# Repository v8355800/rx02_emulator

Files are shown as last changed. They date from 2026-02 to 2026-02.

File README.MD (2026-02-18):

<h1 align="center"> Эмулятор "ГМД-70"/"ГМД-7012" для ЭВМ "Электроника-60"</h1>
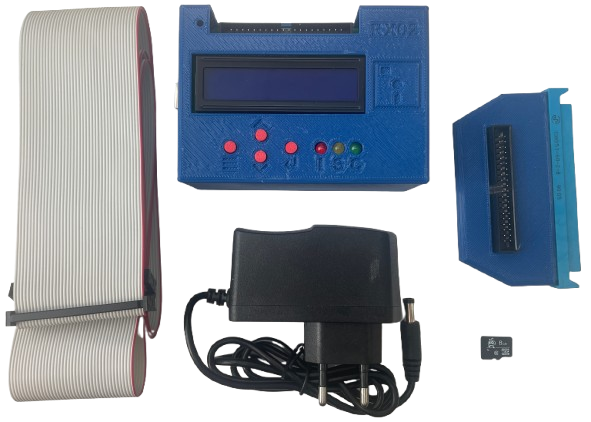
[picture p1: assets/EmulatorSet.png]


##  Оглавление
* [Описание](#description)
* [Комплектация](#equipment)
* [Принцип работы](#operating)
* [Изготовление](#manufacturing)
    * [Покупка компонентов](#manufacturing_buy)
    * [Печатные платы](#manufacturing_pcb)
        * ['Адаптер'](#manufacturing_pcb_adapter)
        * ['Эмулятор'](#manufacturing_pcb_emulator)
    * [Сборка 'Адаптера'](#manufacturing_adapter_assembly)
    * [Сборка 'Эмулятора'](#manufacturing_emulator_assembly)
    * [Жгут](#manufacturing_cable)
* [Корпус](#manufacturing_case)
* [Прошивка](#firmware)
* [Проверка работоспособности](#test)

## Описание
Устройство позволяет отказаться от использования накопителя `"ГМД-70"`/`"ГМД-7012"` (далее НГМД) в составе ЭВМ `"Электроника-60"`, заменив загрузку с дискет на загрузку с образов.
Образы дисков хранятся на `MicroSD` карте. 
"Эмулятор" представляет собой `"Arduino Shield"` (плата расширения) на базе `Arduino Mega2560`.

Ключевое преимущество прибора — автономность, обеспечивающая выбор нужных образов напрямую через само устройство, не требуя подключения к компьютеру.

## Комплектация
- "Эмулятор"
- "Адаптер" (для подключения "Эмулятора" к плате "И-4" в составе ЭВМ)
- Жгут (соединяет эмулятор с адаптером)
- Блок питания
    * 9V DC
    * &#8805;500mA
    * Jack 5.5x2.1
    * полярность - прямая ("+" по центру)
- MicroSD card
    * 8GB
    * SDHC

## Принцип работы
Для понимания можно провести простую аналогию: 
при использовании реального накопителя оператор устанавливает дискету в один или оба доступных отсеков.
То же самое и с эмулятором. Через меню выбирается образ, который устанавливается в виртуальный отсек `[0]` или `[1]`. 
Проще говоря: вместо установки дискет указывается нужный образ в выбранном отсеке.

> [!TIP]  
> Для ЭВМ данный эмулятор выглядит точно так же как и физический накопитель. 

## Изготовление

### Покупка компонентов
Купить компоненты можно на "ChipDip", "Ozon", "WB", "Aliexpress".
Обычно удобно всю мелочевку купить на "ChipDip", а остальное на маркетплейсах.

BOM-файл "Адаптер": [Интерактивный](https://v8355800.github.io/rx02_emulator/assets/bom/RX02_Adapter_ibom_v1.1.html) / [CSV](assets/bom/RX02_Emulator_bom_v1.2.csv)  
BOM-файл "Эмулятор": [Интерактивный](https://v8355800.github.io/rx02_emulator/assets/bom/RX02_Emulator_ibom_v1.2.html) / [CSV](assets/bom/RX02_Emulator_bom_v1.2.csv)

[Ссылка на "Корзину" в "ChipDip"](https://www.chipdip.ru/cart/share/P7Al1Tl6KI5sdudKpMeFdJT3irWuv8lbFa3mm7L9Bp3oRmtGSJEMUTi2QN5kUsKruICHdr5GWGdcOhvIBDb02yR9f8PagUMRVEMTWNeX60IBFPVu2m0RJdy3djSNJDYW2)  
[Excel-таблица покупок](assets/bom/Buy.xlsx)

> [!NOTE]  
> Количество компонентов указано для 10 комплектов.

### Печатные платы
"Адаптер" и "Эмулятор" выполнены в виде двусторонних печатных плат под THT(выводные) компоненты, что упрощает процесс ручной сборки.
Размер плат не превышает `100x100mm`, поскольку многие производства предлагают существенные скидки на платы такого формата.
Заказать печатные платы можно на любом производстве (Резонит, JLCPCB и т.д.).
Параметры: `2 слоя, FR4 1.6mm, 1 Oz (35 µm), HASL, Зеленая маска, Белая шелкография`.  
Gerber-файлы находятся в папке ["gerbers"](gerbers/).

**"Адаптер" - [Gerber-файлы](gerbers/rx02-emulator-adapter_v1.1.zip)**
|Верх|Низ|
|:-:|:-:|
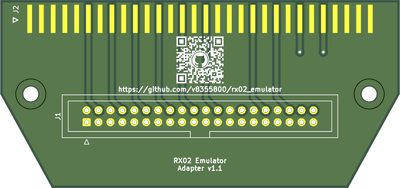
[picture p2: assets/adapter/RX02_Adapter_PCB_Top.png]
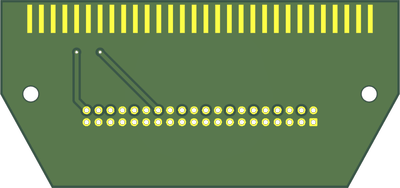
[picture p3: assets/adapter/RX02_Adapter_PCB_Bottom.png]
|||

**"Эмулятор" - [Gerber-файлы](gerbers/rx02-emulator-mega-shield_v1.2.zip)**
|Верх|Низ|
|:-:|:-:|
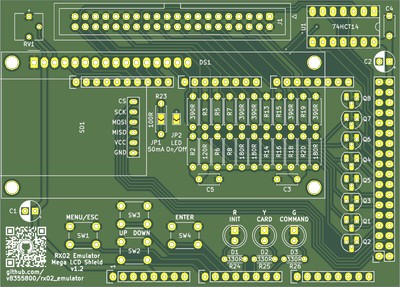
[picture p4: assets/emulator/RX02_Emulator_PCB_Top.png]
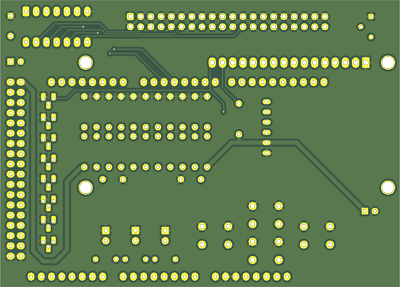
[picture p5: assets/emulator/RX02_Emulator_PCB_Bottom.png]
|||

### Сборка "Адаптера"
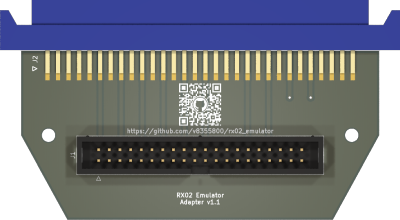
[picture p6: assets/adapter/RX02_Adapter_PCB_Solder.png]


### Сборка "Эмулятора"
|Верх|Низ|
|:-:|:-:|
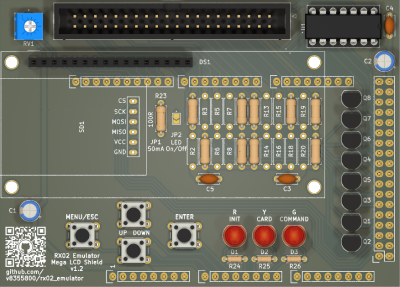
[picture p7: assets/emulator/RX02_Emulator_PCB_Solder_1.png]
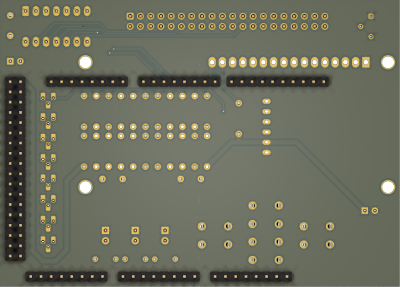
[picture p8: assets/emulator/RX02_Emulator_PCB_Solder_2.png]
|||

**"U1" Микросхема**

||Микросхема|
|:-:|:-|
|Предпочтительно|`74HCT14`, `74AHCT14`|
|Приемлемо|`74HC14`, `74AHC14`|
|Не подходит|`7414`, `74LS14`, `74ALS14`, `74xx04` (any technology)|

Схема устанавливается по ключу (полукруглая выемка на микросхеме). 

**"R1-R22" Termination resistor table**\
Шелкография на плате облегчает определение какие резисторы требуется устанавливать. Если указан номинал, то резистор устанавливается, если нет, то установка не производится.

|Сигнал|Резистор|Номинал||Сигнал|Резистор|Номинал|
|:-----:|:---:|:----:|-|:-----:|:---:|:----:|
|RX_DMA_MODE_H|R1|390||RX_DONE_L|R13|-|
||R2|-|||R14|-|
|RX_AC_L|R3|-||RX_XFER_RQST_L|R15|-|
||R4|120|||R16|-|
|RX_OUT_L|R5|-||RX_INIT_L|R17|390|
||R6|-|||R18|-|
|RX_SHIFT_L|R7|-||RX_ERROR_L|R19|-|
||R8|-|||R20|-|
|RX_12_BIT_L|R9|390||RX_RUN_L|R21|390|
||R10|180|||R22|180|
|RX_DATA_L|R11|390|
||R12|180|

**"D1-D3" Светодиоды**\
Длина ножки `Анода` светодиодов, указанных в `BOM` составляет `16мм`. Нужно запаять так, чтобы они максимально выступали над платой, что обеспечит совпадение с отверстиями в корпусе.

|Светодиод|Цвет|Назначение|Описание|
|:-:|:-:|:-:|:-:|
|D1|Красный|INIT|**ON** - `INIT` устанавливается хостом или ошибка в эмуляторе.<br>**OFF** - в начале команды.|
|D2|Желтый|CARD|**ON** - эмулятор обращается к `MicroSD` карте.<br>**OFF** в противном случае.|
|D3|Зеленый|COMMAND|**ON** - хост отправляет команду.<br>**OFF** - команда выполнена (`DONE` установлен).|

Во время нормальной работы `D2`, `D3` быстро мигают или в основном горят. Для команд, не связанных с хранением (например заполнение/очистка буфера) будет включен только `D3`.

**"JP1" Перемычка**  
Используется для регулирования тока подсветки экрана `LCD1602`.  
Замкнута - ток проходит без ограничений.  
Разомкнута - в цепь включается токоограничивающий резистор `R23`.  
Номинал `R23` составляет `100 Ом`, что обеспечивает максимальный ток подсветки — `50 мА`.  
По умолчанию перемычка не запаивается, резистор `R23` устанавливается.

**"JP2" Перемычка**  
Используется для выбора метода управления подсветкой дисплея `LCD1602`.  
Замкнута - подсветка дисплея постоянно включена, установка транзистора `Q8` не требуется.  
Разомкнута - подсветкой управляет Arduino, требуется установка транзистора `Q8`.  
По умолчанию перемычка не запаивается.

**"P1-P7" Штырьевые разъемы**  
`PLS`, `PLD` запаиваются с нижней стороны платы. С помощью кусачек нарезаются `PLS-40` и `PLD-40` нужной длины.
|Pos|Type|Num|
|:-:|:-:|:-:|
|P1|PLD|36|
|P5|PLS|10|
|P2-P4, P6-P7|PLS|8|

**"SD1" SPI адаптер карт MicroSD**
|MicroSD|Сборка 1|Сборка 2|
|:-:|:-:|:-:|
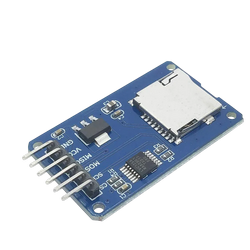
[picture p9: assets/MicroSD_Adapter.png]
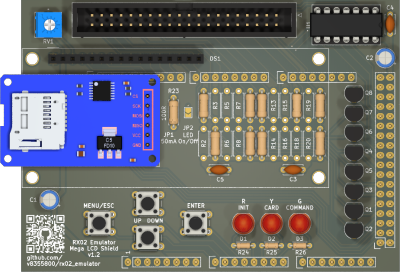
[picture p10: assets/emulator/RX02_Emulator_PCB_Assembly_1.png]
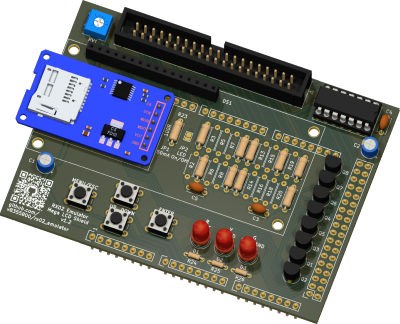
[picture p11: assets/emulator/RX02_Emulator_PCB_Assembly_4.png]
||||

Необходимо выпаять угловой разъем который установлен с завода на плате адаптера. На его место снизу запаять `PLS-6`. Затем впаять в печатную плату на место `SD1`. Нужно выдержать горизонтальность. Этого можно легко добиться, если во время пайки между платой и адаптером подложить спейсеры (черные квадратики которые можно снять с углового разъема, если вытащить пины).

> [!WARNING]
> Если при включении устройство зависает на экране с номером версии прошивки, то убедиться что `MicroSD` карта установлена.

**"DS1" Символьный дисплей LCD1602 (2 строки по 16 символов)**
|LCD1602|Сборка 1|
|:-:|:-:|
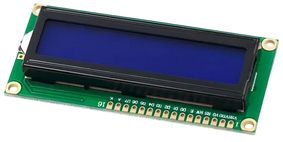
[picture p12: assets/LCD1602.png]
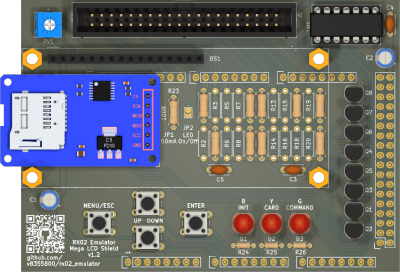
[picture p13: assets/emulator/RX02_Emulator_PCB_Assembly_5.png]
|||

|Сборка 2|Сборка 3|
|:-:|:-:|
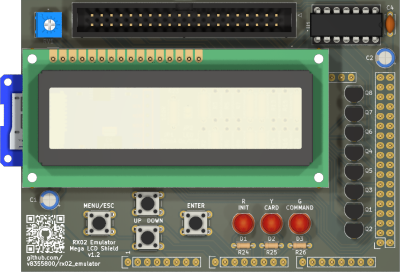
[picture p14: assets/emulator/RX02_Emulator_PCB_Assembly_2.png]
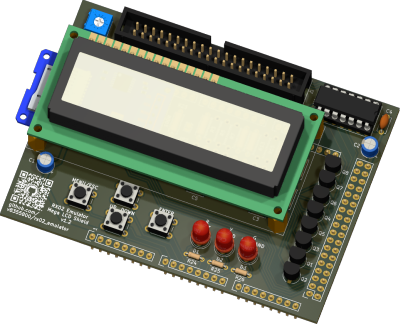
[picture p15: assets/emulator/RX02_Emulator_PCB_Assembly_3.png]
||

На место `DS1` печатной платы сверху запаять гнездо `PBS-16`. На `LCD1602` снизу запаять вилку `PLS-16`.
При установке дисплея на плату в четырех углах между платой и дисплеем установить стойки длиной `11мм`. Закрепить стойки к печатной плате и дисплею с помощью восьми винтов `М3`.

> [!TIP]
> Модификация с модулем `I<sup>2</sup>C` не нужна.

> [!WARNING]
> При первом включении необходимо отрегулировать контрастность дисплея с помощью подстроечного резистора `RV1`. Это можно сделать через имеющееся отверстие в корпусе с помощью крестовой отвертки. В противном случае на дисплее может ничего не отображаться и будет казаться, что устройство не работает.

### Жгут
|Кремпер|IDC-40F|
|:-:|:-:|
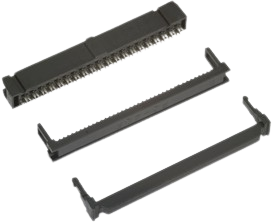
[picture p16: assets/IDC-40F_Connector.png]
|||

На плоский шлейф нужной длины установить с обоих концов розетки `IDC-40F`. Это можно сделать используя специальный кримпер для обжима или с помощью подручных средств. Важно следить чтобы ключ первого контакта на обоих разъемах совпадал с первым проводом шлейфа (обычно помечен красным цветом).  

> [!WARNING]
> Рекомендованная длина жгута - `0.5÷1.5м`.

## Корпус
|Адаптер|Эмулятор|
|:-:|:-:|
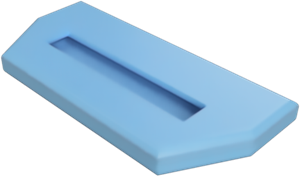
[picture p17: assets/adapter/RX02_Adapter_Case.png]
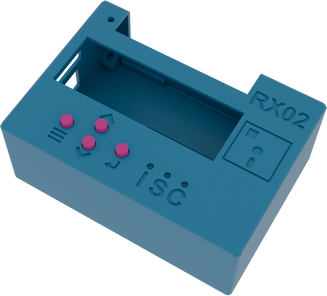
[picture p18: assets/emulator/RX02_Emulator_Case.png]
|||

Корпуса для "Эмулятора" и "Адаптера" можно распечатать на 3D-принтере.

STL-файлы для печати находятся в папке ["3D"](assets/3D):
* Корпус "Адаптера"  
    * [Верхняя крышка](assets/3D/RX02_Adapter_Top.stl)
    * [Нижняя крышка](assets/3D/RX02_Adapter_Bottom.stl)
* Корпус "Эмулятора"  
    * Верхняя крышка: [(Китайский клон)](assets/3D/RX02_Shield_Body_CH340.stl)/[(Оригинал Arduino)](assets/3D/RX02_Shield_Body_Orig.stl)
    * [Нижняя крышка](assets/3D/RX02_Shield_Lid.stl)
    * [Кнопки меню (4шт.)](assets/3D/RX02_Shield_Button.stl)

> [!NOTE]  
> Верхняя крышка "Эмулятора" различается для китайского клона "Arduino Mega 2560 R3 (USB CH340)" и оригинальной версии. Различия заключаются в расположении боковых вырезов. Скорее всего вам понадобиться вариант для клона.

> [!TIP]  
> Поддержки можно не использовать.  
> Для фиксации нижней крышки "Эмулятора" используется саморез `M3`.  
> Для 10 комплектов корпусов хватит одной катушки 1кг.

## Прошивка
Я использую «Arduino-совместимые» китайские платы, у которой для подключения по USB используется контроллер CH340/CH341. Чтобы он распознавался компьютером, нужно установить [`драйвер`](https://wch-ic.com/downloads/CH341SER_EXE.html). Если используется плата с другим контроллером, то нужно установить другой драйвер, соответствующий контроллеру конкретной платы.

Плата подключается к компьютеру по USB с помощью кабеля USB Type-B, на ней должны замигать светодиоды. Компьютер издаст характерный сигнал подключения нового оборудования, а при первом подключении появится окошко “Установка нового оборудования”.

В системе появиться новый COM порт с произвольным номером. Проверить можно через "Диспетчер устройств" в разделе "Порты (COM и LPT)".

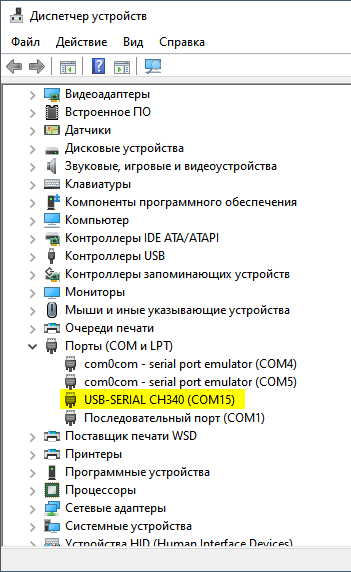
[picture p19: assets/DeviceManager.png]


С помощью [`"xLoader"`](https://github.com/binaryupdates/xLoader) загрузить прошивку из папки [`"firmware"`](firmware/) на устройство.  
* Hex file: [`"rx02_emulator_lcd_and_buttons v2.1.hex"`](firmware/rx02_emulator_lcd_and_buttons%20v2.1.hex)
* Device: `Mega(ATMEGA2560)`
* COM port: `порт Arduino`
* Baud rate: `115200`
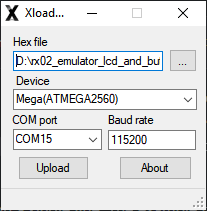
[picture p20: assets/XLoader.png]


## Проверка работоспособности
* Подключить эмулятор с помощью адаптера к плате "И-4" вместо "НГМД".
* Записать образы ОС ["RT-11.DSK"](test/RT-11.dsk) и ["TMOS.dsk"](test/TMOS.dsk) на MicroSD карту из папки ["Test"](test/).
* Установить MicroSD карту в эмулятор.
* Подключить питание к эмулятору с помощью блока питания.
* В меню выбрать образы ОС для `[0]` и `[1]` отсеков.
* Проверить загрузку ОС с образа в `[0]` отсеке.
* Проверить загрузку ОС с образа в `[1]` отсеке:  
    ```
    R2/100267
    173004G
    ```

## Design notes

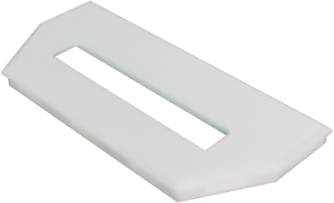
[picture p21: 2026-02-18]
assets/adapter/RX02_Adapter_Case_Top.png

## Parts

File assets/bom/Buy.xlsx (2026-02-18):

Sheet: Итого
Магазин | Номенклатура | Кол-во
OZON | Пластик для 3D принтера Start PETG (1кг, 1.75мм, синий) на пластиковой катушке | 1
 | SmartBuy High Speed 8 ГБ Карта памяти microSDHC, с адаптером, SB8GBSDCL10-01, черная | 10
 | Винты PWM3x5 для крепления материнской платы/DVD/SSD 2,5" черные 50шт | 2
ipelectron | СНО53-60/95х9Р-2-В Розетка прямая, врубная, "1" (OP-1086) | 10
 | Доставка | 1
Aliexpress | LCD1602 LCD module | 10
 | AC 110-240V DC 9V 5.5-2.1MM | 10
 | MEGA2560 MEGA 2560 R3 (CH340) | 10
 | Micro SD Storage Expansion Board | 10
ChipDip | SN74HCT14N, Микросхема, Шесть инвертирующих триггеров Шмитта [DIP-14.]\Texas Instruments | 10
 | 3362P 10K, Резистор\RUICHI | 10
 | К10-17Б 0.1мкФ X7R, 10%, 0805, JYM1H104KBX010000B, Конденсатор керамический выводной | 30
 | ECAP (К50-35 мини), 33мкФ, 25В, 5х7мм, JRK1E330M02000500070000B | 20
 | GNL-5012YD, Светодиод желтый 60° d=5мм 7мКд 585нМ (Yellow) | 10
 | PBS-16 (DS-1023 - 1x16), Гнездо на плату 2.54мм 1х16pin прямое | 10
 | PLD-40 (DS-1021- 2x20), Вилка штыревая 2.54мм 2х20pin прямая тип1 | 10
 | PLS-40 (DS1021-1x40), Вилка штыревая 2.54мм 1х40pin прямая тип1 | 20
 | IDC-40F (DS1016-40), Розетка 2.54мм на шлейф 40 pin с фиксатором кабеля | 20
 | BH-40 (DS1013-40S) (IDC-40MS), Вилка на плату прямая 40pin 2.54мм | 20
 | KLS7-TS6601-4.3-180, Кнопка тактовая h=4.3мм | 40
 | TRS-14 (SCSM-14) (DS1001-01-14N), DIP панель 14-контактная цанговая узкая | 10
 | KLS8-DBK-M3-E5.0-L11 (PCHSS-11), Стойка для печатных плат, шестигранная, М3, 11мм | 40
 | CF-25 (С1-4) 0.25Вт, 120 Ом, 5%, Резистор углеродистый | 10
 | CF-25 (С1-4) 0.25Вт, 180 Ом, 5%, Резистор углеродистый | 30
 | CF-25 (С1-4) 0.25Вт, 100 Ом, 5%, Резистор углеродистый | 10
 | CF-25 (С1-4) 0.25Вт, 390 Ом, 5%, Резистор углеродистый | 50
 | CF-25 (С1-4) 0.25Вт, 330 Ом, 5%, Резистор углеродистый | 30
 | 2N7000, Транзистор, N-канал, 60В, 0.2А [TO-92] | 80
 | GNL-5012GD, Светодиод зеленый 60° d=5мм 8мКд 565нМ (Green) | 10
 | Шлейф плоский серый FRC- 40 х 0,08 (28 AWG) 30,5 м | 1
 | GNL-5012HD, Светодиод красный 60° d=5мм 3мКд 700нМ (Red) | 10

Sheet: ChipDip
Магазин | Номенклатура | Номенклатурный номер | Артикул | Кол-во
ChipDip | SN74HCT14N, Микросхема, Шесть инвертирующих триггеров Шмитта [DIP-14.]\Texas Instruments | 8494302034 | SN74HCT14N | 10
 | 3362P 10K, Резистор\RUICHI | 8022445200 | 3362P 10K | 10
 | К10-17Б 0.1мкФ X7R, 10%, 0805, JYM1H104KBX010000B, Конденсатор керамический выводной | 9001397245 | JYM1H104KBX010000B | 30
 | ECAP (К50-35 мини), 33мкФ, 25В, 5х7мм, JRK1E330M02000500070000B | 8512 | JRK1E330M02000500070000B | 20
 | GNL-5012YD, Светодиод желтый 60° d=5мм 7мКд 585нМ (Yellow) | 9000422974 | GNL-5012YD | 10
 | PBS-16 (DS-1023 - 1x16), Гнездо на плату 2.54мм 1х16pin прямое | 48816 | PBS-16 (DS-1023 - 1x16) | 10
 | PLD-40 (DS-1021- 2x20), Вилка штыревая 2.54мм 2х20pin прямая тип1 | 250743391 | PLD-40 (DS-1021- 2x20) | 10
 | PLS-40 (DS1021-1x40), Вилка штыревая 2.54мм 1х40pin прямая тип1 | 39606 | PLS-40 (DS1021-1x40) | 20
 | IDC-40F (DS1016-40), Розетка 2.54мм на шлейф 40 pin с фиксатором кабеля | 49806 | IDC-40F (DS1016-40) | 20
 | BH-40 (DS1013-40S) (IDC-40MS), Вилка на плату прямая 40pin 2.54мм | 57941 | BH-40 (DS1013-40S) (IDC-40MS) | 20
 | KLS7-TS6601-4.3-180, Кнопка тактовая h=4.3мм | 9000336830 | KLS7-TS6601-4.3-180 | 40
 | TRS-14 (SCSM-14) (DS1001-01-14N), DIP панель 14-контактная цанговая узкая | 14398 | TRS-14 (SCSM-14) (DS1001-01-14N) | 10
 | KLS8-DBK-M3-E5.0-L11 (PCHSS-11), Стойка для печатных плат, шестигранная, М3, 11мм | 9000443090 | KLS8-DBK-M3-E5.0-L11 (PCHSS-11) | 40
 | CF-25 (С1-4) 0.25Вт, 120 Ом, 5%, Резистор углеродистый | 266 | CF-25 (С1-4) 0.25Вт, 120 Ом, 5% | 10
 | CF-25 (С1-4) 0.25Вт, 180 Ом, 5%, Резистор углеродистый | 105 | CF-25 (С1-4) 0.25Вт, 180 Ом, 5% | 30
 | CF-25 (С1-4) 0.25Вт, 100 Ом, 5%, Резистор углеродистый | 28024 | CF-25 (С1-4) 0.25Вт, 100 Ом, 5% | 10
 | CF-25 (С1-4) 0.25Вт, 390 Ом, 5%, Резистор углеродистый | 9320 | CF-25 (С1-4) 0.25Вт, 390 Ом, 5% | 50
 | CF-25 (С1-4) 0.25Вт, 330 Ом, 5%, Резистор углеродистый | 31912 | CF-25 (С1-4) 0.25Вт, 330 Ом, 5% | 30
 | 2N7000, Транзистор, N-канал, 60В, 0.2А [TO-92] | 9000980590 | 2N7000 | 80
 | GNL-5012GD, Светодиод зеленый 60° d=5мм 8мКд 565нМ (Green) | 9000422973 | GNL-5012GD | 10
 | Шлейф плоский серый FRC- 40 х 0,08 (28 AWG) 30,5 м | 8007264679 |  | 1
 | GNL-5012HD, Светодиод красный 60° d=5мм 3мКд 700нМ (Red) | 9000422972 | GNL-5012HD | 10

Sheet: OZON
Магазин | Номенклатура | Артикул | Кол-во
OZON | Пластик для 3D принтера Start PETG (1кг, 1.75мм, синий) на пластиковой катушке | 2631497744 | 1
 | SmartBuy High Speed 8 ГБ Карта памяти microSDHC, с адаптером, SB8GBSDCL10-01, черная | 1580216671 | 10
 | Винты PWM3x5 для крепления материнской платы/DVD/SSD 2,5" черные 50шт | 1726831742 | 2

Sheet: Aliexpress
Магазин | Номенклатура | Кол-во
Aliexpress | LCD1602 LCD module | 10
 | AC 110-240V DC 9V 5.5-2.1MM | 10
 | MEGA2560 MEGA 2560 R3 (CH340) | 10
 | Micro SD Storage Expansion Board | 10

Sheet: ipelectron
Магазин | Номенклатура | Артикул | Кол-во
ipelectron | СНО53-60/95х9Р-2-В Розетка прямая, врубная, "1" (OP-1086) | OP-1086 | 10
 | Доставка |  | 1
Минимальный заказ 1000 руб + Доставка
Можно другой артикул: SN-7818

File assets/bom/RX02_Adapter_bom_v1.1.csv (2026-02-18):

Designator | Footprint | Quantity | Value | LCSC Part #
J1 | IDC-Header_2x20_P2.54mm_Vertical | 1 | IDC-40
J2 | CHO53-60 | 1 | CHO53-60

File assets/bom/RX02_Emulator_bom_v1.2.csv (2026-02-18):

Designator | Footprint | Quantity | Value | LCSC Part #
C1, C2 | CP_Radial_D5.0mm_P2.50mm | 2 | 33uf
C3, C4, C5 | C_Disc_D5.0mm_W2.5mm_P5.00mm | 3 | 0.1uf
D1 | LED_D5.0mm | 1 | INIT
D2 | LED_D5.0mm | 1 | CARD
D3 | LED_D5.0mm | 1 | COMMAND
DS1 | WC1602A | 1 | WC1602A
J1 | IDC-Header_2x20_P2.54mm_Vertical | 1 | Conn_02x20_Odd_Even
JP1, JP2 | SolderJumper-2_P1.3mm_Open_TrianglePad1.0x1.5mm | 2 | SolderJumper_2_Open
P1 | Socket_Strip_Arduino_2x18 | 1 | Digital
P2 | Socket_Strip_Arduino_1x08 | 1 | Power
P3, P4 | Socket_Strip_Arduino_1x08 | 2 | Analog
P5 | Socket_Strip_Arduino_1x10 | 1 | PWM
P6 | Socket_Strip_Arduino_1x08 | 1 | PWM
P7 | Socket_Strip_Arduino_1x08 | 1 | Communication
Q1, Q2, Q3, Q4, Q5, Q6, Q7, Q8 | TO-92_HandSolder | 8 | 2N7000
R1, R11, R13, R15, R17, R19, R21, R3, R5, R7, R9 | R_Axial_DIN0207_L6.3mm_D2.5mm_P7.62mm_Horizontal | 11 | 390R
R10, R12, R14, R16, R18, R2, R20, R22, R6, R8 | R_Axial_DIN0207_L6.3mm_D2.5mm_P7.62mm_Horizontal | 10 | 180R
R23 | R_Axial_DIN0207_L6.3mm_D2.5mm_P7.62mm_Horizontal | 1 | 100R
R24, R25, R26 | R_Axial_DIN0204_L3.6mm_D1.6mm_P5.08mm_Horizontal | 3 | 330R
R4 | R_Axial_DIN0207_L6.3mm_D2.5mm_P7.62mm_Horizontal | 1 | 120R
RV1 | TRIM_3362P-1-103 | 1 | 10K
SD1 | Catalex-MicroSD-Card-Up-No-Holes | 1 | CARD-SD-ADAPTER-CATALEX
SW1 | SW_PUSH_6mm_H4.3mm | 1 | MENU/ESC
SW2 | SW_PUSH_6mm_H4.3mm | 1 | DOWN
SW3 | SW_PUSH_6mm_H4.3mm | 1 | UP
SW4 | SW_PUSH_6mm_H4.3mm | 1 | ENTER
U1 | DIP-14_W7.62mm_Socket_LongPads | 1 | 74HCT14

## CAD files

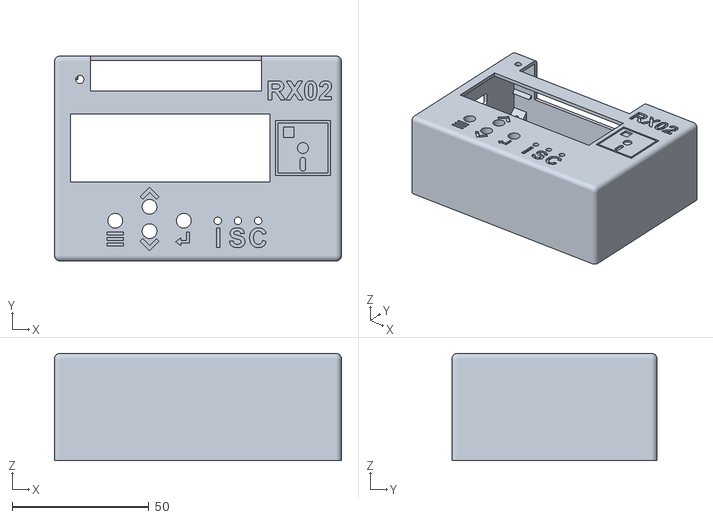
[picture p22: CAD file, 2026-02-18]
assets/3D/RX02_Shield_Body_CH340.stl
105.0 x 75.0 x 39.3

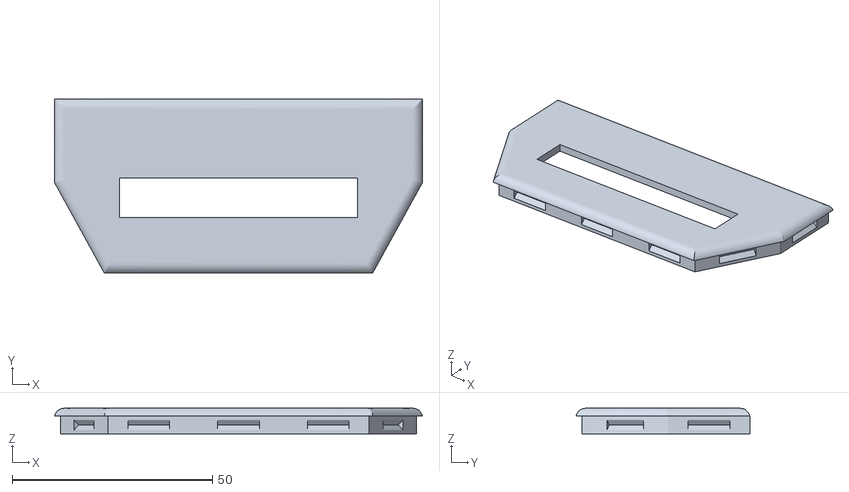
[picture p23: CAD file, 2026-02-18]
assets/3D/RX02_Adapter_Top.stl
92.0 x 43.5 x 6.40

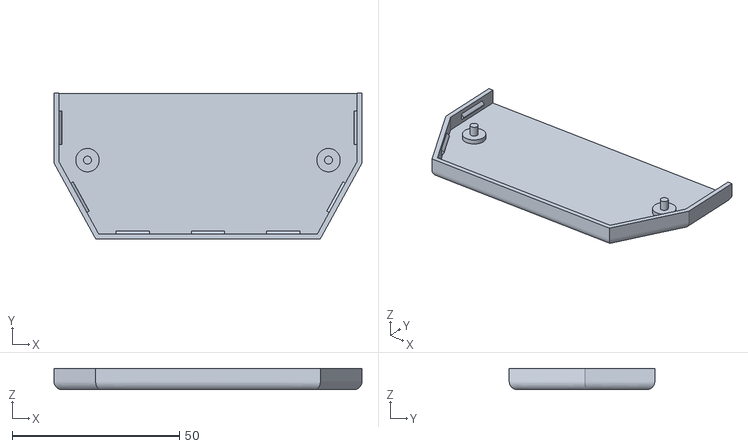
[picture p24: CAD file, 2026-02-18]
assets/3D/RX02_Adapter_Bottom.stl
92.0 x 43.5 x 6.40

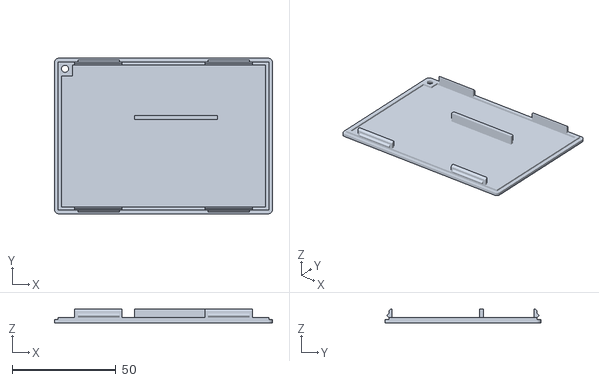
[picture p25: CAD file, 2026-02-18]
assets/3D/RX02_Shield_Lid.stl
105.2 x 75.1 x 6.60

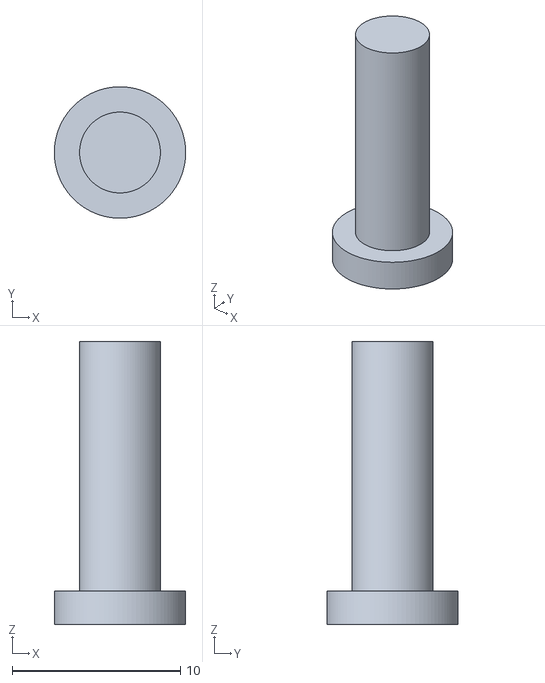
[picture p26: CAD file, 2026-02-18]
assets/3D/RX02_Shield_Button.stl
7.80 x 7.80 x 16.8

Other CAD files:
assets/3D/RX02_Shield_Body_Orig.stl

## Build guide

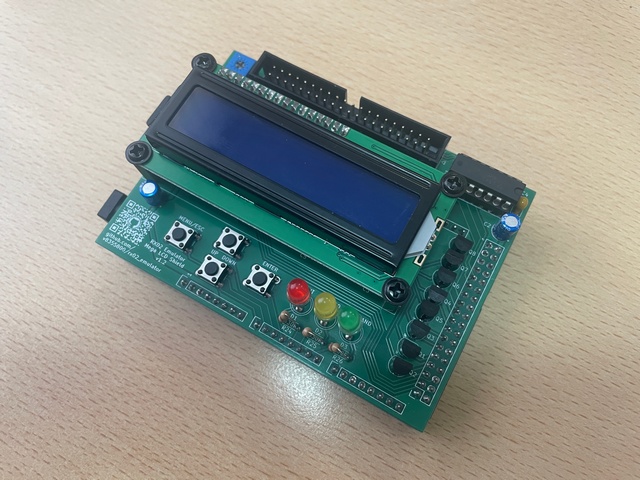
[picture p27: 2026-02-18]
assets/emulator/RX02_Emulator_PCB_Assembly_Photo_Full.JPG
